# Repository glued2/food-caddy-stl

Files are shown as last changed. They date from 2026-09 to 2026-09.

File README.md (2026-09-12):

# Food caddy R4 — ALL PRINTED

**No purchased fasteners, metal pins, nuts or structural glue.** The bin,
hangers, flip hinge, axle, positive retainers, bag frame and fit-gauge keys
all print on the K1 SE. No brims or G-code.

This hangs **inside one end of the LEFT recycling bin** in the pullout
drawer, resting on the recessed internal ledge—not clamping the external
flange. The remaining recycling area stays accessible when the lid is closed.
Actual host fit, safe load and kitchen clearance remain **unverified**.

## Current print files — coupons first

- **[Full ALL-PRINTED ZIP](packages/food-caddy-r4-ALL-PRINTED-FULL.zip)**:
  three production print jobs, one combined test job, individual spares, guide and
  machine-readable validation. “Full” means a package, not one giant plate.
- **[R4 guide](docs/R4_GUIDE.md)**: read for coupon sequence, every assembly
  and removal path, keeper orientations, print orientation and local supports.
- **[Production/test plates](production)** and **[individual spares](spares)**.
- **[NO-RAILS accessory ZIP](packages/food-caddy-r4-ALL-PRINTED-NO-RAILS.zip)**:
  one combined alternative plate with liner frame, moving leaf, three standard
  keepers, long rear keeper, axle and axle-lock gate. **Excludes bin, lid, BOTH R4 hanging brackets,
  fixed rear R4 hinge rail and all coupons.** Repeat prints for identical R4
  fittings already in hand only; never compatible with R3 or legacy parts.

The complete assembly has **13 printed pieces**. The production plates
include all required quantities, including three standard keepers and one
long rear keeper. The combined test plate includes the gauge's two **short** keepers;
those short keys must not be used on the caddy.

Print `production/r4-test-fit-kit.stl` first. It combines the gauge and mating
coupons. Then print `production/r4-03-accessories.stl` and test the real fittings
on those coupons before the large `r4-01-bin.stl` and `r4-02-lid.stl` jobs.
The accessory parts sit inside the open liner frame, with at least 5 mm between
their projected footprints; no part shape or orientation has changed.
Use layer-by-layer printing, NOT sequential/complete-individual-object mode.
Localized supports must stay inside the available gaps in the slicer preview.
Individual spares remain available; they are not extra required print jobs.

### Structural redesign, not printed replacement M4 bolts

- Integral broad body dovetails and matching stopped hanger slides carry
  waste weight through sloped bearing seats. Small keys do **not** carry
  the main hanging load. No flexible snap fingers or friction-only joints.
- Solid printed bayonet keepers insert freely, then quarter-turn into
  positive withdrawal stops. A wide lid dovetail captures its moving leaf.
- An **8 mm printed axle** carries the lid only. Its integral head and
  cross-wing retain it axially; a separate **rigid axle-lock gate** prevents
  rotation back to release. A long rear keeper locks that gate in place.
- A removable continuous bag-retainer frame sits on the bin's integral
  ramped shelf. The lid really flips and seats directly on the rim.

## Dimensions and critical assumptions

| Dimension | Current design |
|---|---|
| Full assembly | **230 x 210.5 x 219 mm** |
| Body shell top / bottom | **204 x 190 / 190 x 174 mm** |
| Body height / floor | **200 / 3 mm** |
| Minimum true normal wall, including chamfers | **>=2.496 mm** |
| Straight top corner chamfer | **35 mm** |
| Internal ledge support plane | **216 mm above floor** |
| Body rim recess below support / closed projection above | **16 / 3 mm** |

**230 is total outside width INCLUDING ledges, not the host opening.**
The working opening assumption is **224, unmeasured**, leaving only **3 mm
nominal bearing each side**. The reported 18 mm ledge dimension is a
vertical height, not flange thickness to clamp. Exact taper, internal step,
floor datum and cabinet clearances cannot be inferred from the photo.

Measure the actual internal bearing surfaces and use the printed split
gauge and real joint coupons before spending filament on the bin. The
16 mm recess is a design choice, not a measured step. Prefer the hinge
facing the remaining recycling space; opening requires roughly **195 mm
above the internal ledge** and **54 mm behind the closed hinge end**, plus
clearance. Check the fully extended drawer, shelf/counter and adjacent bin.

## Printing and validation

K1 SE **220 x 220 x 250**, 100% scale, supplied orientations, >=2 mm
plate-edge margin. PLA on a prepared/glued bed; **no brim**. Bin and broad
flat lid pass a support-free downward-face test. Some small-part transverse
head recesses may need **localized removable supports**, as specified in
the guide. Keepers and axle print **horizontally on broad flats**, not upright.

```powershell
npm ci
npm run build
npm test
# In a Python environment with numpy and trimesh:
python source\r4\validate_stl.py
```

Source: `source/r4/generate.mjs`, pinned Manifold WASM CSG. Build writes only
current `production`, `spares`, `packages` and the existing guide bytes.
`npm test` regenerates in memory and checks exact deterministic output/ZIP
parity without rewriting. Tests cover outward single solids, true wall/floor,
per-part bed contact, plate/spare identity and gaps, bearing contact, slide
and bayonet trajectories, positive stops, gate anti-rotation, lid seating
and a full 0–110° movement sweep including all retainers.
See [validation](packages/r4-validation.json) and [manifest](packages/r4-manifest.json).
No mesh is silently repaired. CAD checks are not physical print success,
a load rating, layer-bond validation or a PLA creep-life guarantee.

## Two preserved alternatives — do not mix fittings

**[metal-screws-required](metal-screws-required/FALLBACK_NOTE.md)** contains the
complete valid-but-hardware-dependent **R3 fallback** from commit
`b736c3d7db481300fadee53dfdf104b7b42ae97f`. All 59 original source/doc/STL/ZIP
and dependency files are preserved byte-for-byte with hashes. Its build runs
from that folder; use its small `RUN_AUDIT.py` wrapper for the independent
audit in its new nested location. This fallback is not the unsafe legacy set.

**[archive/legacy](archive/README.md)** retains the 22 much older files with
known unsafe geometry. Those are historical reference only, not print
recommendations. The independent audit verifies both snapshots remain intact.

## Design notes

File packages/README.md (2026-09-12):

# Current R4 all-printed packages

- `food-caddy-r4-ALL-PRINTED-FULL.zip`: all production parts/coupons,
  three production jobs, one combined test job, individual spares, guide,
  manifest and validation. Start in the `production` folder; spares are optional.
- `food-caddy-r4-ALL-PRINTED-NO-RAILS.zip`: one combined alternative plate:
  liner frame, moving leaf, three standard keepers, long rear keeper, hinge
  axle and axle-lock gate. **Excludes bin,
  lid, BOTH new R4 hangers, fixed R4 hinge rail and all coupons.**
  For repeat prints with identical R4 fittings already printed, never R3.
- `r4-manifest.json`: full-design quantities, hashes and inventory. The
  accessory ZIP includes this catalogue for reference, not all listed parts.
- `r4-validation.json`: actual geometry, bearing, assembly path, retention,
  print-layout and opening checks.

Every fastening, including test-gauge keys, is printable. No bought hardware,
structural glue, brim or G-code. Read `../docs/R4_GUIDE.md` before printing.

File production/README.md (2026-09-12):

# R4 all-printed production and test plates

1. `r4-test-fit-kit.stl`: host gauge, its two short keys and all mating coupons.
2. `r4-03-accessories.stl`: liner frame and every small production fitting.
3. After the gauge and real fittings pass the guide's checks, print
   `r4-01-bin.stl` and `r4-02-lid.stl`, one job each.

The three production jobs contain all 13 required printed pieces. No metal
hardware or structural glue is needed. Use the supplied orientations;
read `../docs/R4_GUIDE.md` for localized support decisions and assembly order.
There is no brim or G-code. No R3/legacy part is compatible.

Use layer-by-layer printing, not sequential printing. Accessories are nested
inside the frame opening without changing their shapes or orientations.
Keep localized supports within the checked gaps; inspect toolpaths in Creality
Print before printing. Use `alternatives/r4-03-accessories-no-rails.stl` INSTEAD
of the full accessories plate only when reusing identical R4 rails.

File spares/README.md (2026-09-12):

# R4 all-printed individual parts and coupons

One STL is one physical copy. Complete caddy quantities are in
`../packages/r4-manifest.json`: notably **3 standard bayonet keepers** and
**1 long rear-gate keeper**. The two **short** gauge keepers belong only to
the host test gauge and must never replace a production keeper.

All parts are already in print orientation. Plates in `../production`
reuse these exact solids by translation. See `../docs/R4_GUIDE.md`.

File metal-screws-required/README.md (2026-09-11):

# Food caddy STL — corrected R3

## Current R3 files only; print fit coupons before the bin

This is an **inset suspended food caddy inside one end of the LEFT recycling
bin in a pullout kitchen drawer**, not an external rim clip. The hanging
ledges rest on the host's **recessed internal bearing ledge** without clamping
its broad outer flange. The roughly 200 mm caddy occupies about one end of
the 400 mm host; the remaining recycling area stays accessible when closed.
Exact usable volume and clearances depend on the actual host.

**Legacy files are UNSAFE historical reference, not current print files.**
All 22 original tracked files—old STL parts, generator, original documentation,
STL ZIP and historical G-code ZIPs—are preserved under
[`archive/legacy`](archive/legacy). Preservation hashes and the original Git
commit are recorded in [`archive/legacy-manifest.json`](archive/legacy-manifest.json).
Their thin/collapsed chamfer walls, overlapping or inverted
shells, and mismatched fittings are not fixed by slicer mesh repair.
**Do not reuse the previously printed hangers or hinge rail with R3.**

R3 is real manifold-3d solid CSG, with separately bolted hanging ledges,
a flat lid and separate hinge leaf, a **metal M5 bolt/locknut axle**, and a
continuous liner frame. It does not depend on glue or a printed friction pin.
**Metal hardware is required**, not included in STL downloads.

- **[Full R3 ZIP](packages/food-caddy-r3-FULL.zip)** — all parts,
  small fit coupons, separate printable plates, guide and validation.
  “Full” means a package of print jobs, not a crowded single plate.
- **[R3 assembly/printing guide](docs/R3_GUIDE.md)** — dimensions, required
  hardware, coupon sequence, supports and limitations. Read this first.
- **[Production/test plates](production)** — five production
  jobs and two test jobs. Import centred, at 100%, millimetres.
- **[Individual parts / spares](spares)** — seven production
  parts plus seven coupons, each in its intended print orientation.
- **[NO-RAILS accessory-only ZIP](packages/food-caddy-r3-accessories-NO-RAILS.zip)**
  — **liner frame and moving hinge leaf ONLY**. Excludes bin, lid, **both
  hanging ledges/brackets, fixed rear hinge rail**, coupons and all hardware.
  This is for identical R3 rail reuse, never old fittings, and is not a
  complete caddy.

The root now contains only the new design's `source/r3`, `docs`, `production`,
`spares` and `packages`; **the archive is not a source of usable spare parts**.
The hanging bin, hinged lid and removable bag-retainer functions are retained.
Significant changes are mechanical M4 mounting joints, a positively retained
metal M5 axle instead of a printed pin/collar, and wholly new hanging/hinge
fittings. No artificial compatibility with already printed legacy parts is
maintained. No-rails means omitting **new R3** rails for repeat prints only.

### Confirmed measurements versus assumptions

230 mm is the host's **total outside left/right width including ledges**,
NOT its clear opening. Actual clear opening is **unmeasured**. R3 assumes
224 for design checks; its ledges span 230 overall (only 3 mm nominal
bearing each side), below-ledge bracket envelope is 220, bin top is
212 x 194, base 192 x 176, body height 205. Corners use 35 mm chamfers.
Full closed assembly is **230 x 206.5 x 224 mm**. The body rim is deliberately
recessed **16 mm below the internal support plane**, keeping the entire
closed assembly, including hardware, **at most 3 mm above that plane**;
the floor is 221 mm below it. This recess is a design choice, not a dimension
measured from the photo. Height relative to the host's outer rim is unknown.

Body wall is a true 2.5 mm polygon offset, giving **minimum 2.4946 mm
normal thickness including tapered chamfers**, with a 3 mm floor.
Lid skin is 2.4 mm, seats directly at rim height, and prints with over
39,000 mm² actual flat contact on the bed.

These dimensions do **not** establish real host fit or safe loading. The
user's approximate “just over 210 at depth 230” and 18 mm ledge height
do not describe the whole taper or ledge profile; 18 mm is a vertical height,
**not flange thickness to grip**. Drawer/shelf clearance and lid-opening
space at the chosen end are also unmeasured. Measure these and test
the split full-span gauge, wall joints and complete small hinge assembly
**before spending filament on the bin**. No physical fit, load rating,
creep life or slicer validation is claimed.

### Slicing summary

K1 SE: 220 x 220 x 250. Supplied layouts have >=2 mm XY edge margin.
PLA on a correctly prepared/glued bed. **No brims, no new G-code.**
Bin and broad flat lid: supports off. The fixed rear hinge rail's horizontal
5.8 mm bores need localized removable supports; other small-part horizontal
M4 holes may need local support depending on coupon results. Use the supplied
orientations and read the full guide. Do not automatically lay hangers on
their projecting ledge tips.

### Source and validation

```powershell
npm ci
npm run build
npm test
# Independent audit, in an environment with numpy and trimesh:
python source\r3\validate_stl.py
```

The generator is `source/r3/generate.mjs`; dependencies are pinned in
`package-lock.json`. It writes directly to `production`, `spares` and `packages`
using a single file manifest, never into `archive`. `npm test` rebuilds in
memory and fails on stale files.

Automated checks cover valid closed outward single-part solids; true
chamfer offsets and continuous floor; individual bed contact; printer margins;
plate separation and translated spare identity; lid seating and assembly
collisions; 0–110° opening at 0.1° intervals; metal axle clearance and positive
retention dimensions; archive parity. Details are in
[`packages/r3-validation.json`](packages/r3-validation.json).
The independent Python audit checks the exported STL topology/winding/volume,
per-component bed contact, triangle-level plate/spare parity, manifest/ZIP
hashes and complete archive preservation against its immutable baseline.
Neither test substitutes for physical
fit, layer adhesion, stress analysis or a slicer preview.

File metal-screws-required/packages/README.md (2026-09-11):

# Current R3 packages

- `food-caddy-r3-FULL.zip`: all seven production parts, seven coupons,
  five production plates and two test plates, guide, manifest and validation.
  This is a package of separate print jobs, not one oversized plate.
- `food-caddy-r3-accessories-NO-RAILS.zip`: **liner frame and moving hinge
  leaf only**. Excludes bin, lid, **both new hanging brackets/ledges and
  the new fixed rear hinge rail**, coupons and all metal hardware.
  Only for repeat prints reusing identical R3 fittings—never archived parts.
- `r3-manifest.json`: full current file inventory and SHA-256 hashes.
  The accessory ZIP includes this full-design catalogue for reference;
  that catalogue does not mean the omitted parts are in the accessory ZIP.
- `r3-validation.json`: dimensions and automated CSG/print/assembly checks.

Read `../docs/R3_GUIDE.md`, measure the unconfirmed host opening, then print
coupons first. Hardware and localized hinge-bore supports are required.
No new G-code or brims. No physical fit or load rating is claimed.

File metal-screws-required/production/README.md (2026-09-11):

# R3 production and test plates

Print the two test jobs and actual small fittings first, then the bin, lid and
liner frame only after checking fit. The five production jobs are separate
plates, not one oversized assembly. Each physical part also exists as an
individual replacement in `../spares/`.

Read [`../docs/R3_GUIDE.md`](../docs/R3_GUIDE.md) for hardware, orientations and
localized supports. No brims or G-code. Old files are isolated in
`../archive/legacy/` and must not be printed or reused with R3.

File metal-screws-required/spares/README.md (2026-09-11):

# R3 individual parts, spares and fit coupons

These 14 STLs comprise seven production parts and seven small coupon parts.
Each is already in its intended print orientation. Production plates in
`../production/` reuse the identical solids, so do not print both unless you
want extra copies.

Read [`../docs/R3_GUIDE.md`](../docs/R3_GUIDE.md) before printing or assembly.
**No R3 part is intended to mate with an archived legacy fitting.** The
no-rails accessory package omits NEW R3 rails for repeat prints only.

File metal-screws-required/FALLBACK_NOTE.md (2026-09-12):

# Preserved R3 fallback — metal screws required

This is the complete R3 deliverable from commit
`b736c3d7db481300fadee53dfdf104b7b42ae97f`, preserved without changing any
original source, STL, ZIP, documentation or dependency-manifest bytes.
`PRESERVATION.json` records all 59 original files and hashes, including a
copy of the original historical archive. The root historical archive was
not modified. This folder is a hardware-dependent fallback, **not the unsafe
legacy design** inside its archive subfolder.

From this folder, `npm ci`, `npm run build`, and `npm test` run normally.
`npm test` is non-writing. To regenerate without changing the preserved
snapshot hashes, first copy this fallback to a separate working folder:
the original generator writes its local outputs and may change ZIP container
timestamps even when the STL geometry is identical.
For the independent audit, use a Python environment containing numpy/trimesh:
`python RUN_AUDIT.py`. The original audit assumes it is at the Git repository
root; this small wrapper adds `git ls-tree --full-tree` for the new nested
location only. The original audit source is unchanged.

The current root R4 design is all-printed. Do not mix R3 and R4 fittings.

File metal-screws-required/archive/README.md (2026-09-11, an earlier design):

# Unsafe historical files — do not print

`legacy/` contains the complete pre-R3 tracked repository: old STL parts,
old generator, original README/assembly notes, STL ZIP, and historical
G-code ZIPs. These are preserved for traceability, **not recommended files**.
Instructions inside that snapshot are obsolete and unsafe to follow.

Use only the current root `production/`, `spares/`, `packages/`, `source/r3/`
and `docs/R3_GUIDE.md`. R3 is a different design; **no old hanging or hinge
fitting is compatible**. No-rails packages refer only to identical R3 fittings.

`legacy-manifest.json` records all 22 original paths, their archived paths,
byte lengths, SHA-256 hashes and immutable source commit. Binary assets and
the old generator were moved without changing their working-tree bytes.
Original README/assembly notes were recovered byte-for-byte from the original
Git commit, before the R3 documentation rewrite. The STL audit verifies the
archive against both these preservation hashes and the immutable Git baseline.

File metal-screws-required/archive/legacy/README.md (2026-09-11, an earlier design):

# Food caddy STL

Parametric food-caddy parts sized for the Creality K1 SE.

## Print set

All files are now the current, standard design (after the reinforcement update following the first test print). Print these as separate jobs from `production\`:

1. `food_caddy_k1se_body_216mm.stl` - not yet printed.
2. `food_caddy_k1se_flip_lid_216mm.stl` - not yet printed; the rear hinge spine and front seating tab now have wider, full-thickness base pads so they can't shear off the lid skin the way the retainer frame tab did.
3. `food_caddy_k1se_liner_hanger_plate.stl` - bag-retainer frame is now a uniform 2.8 mm thickness with flush grip tabs, and the collar is printed standing on its round face so its pin bore is vertical.
4. `food_caddy_k1se_hinge_kit_plate.stl` - unchanged; the rear hinge rail already printed successfully, and this plate also contains the hinge pin.

Alternative accessory plates, useful if you don't want to reprint parts that already came out fine:

- `food_caddy_k1se_accessories_everything.stl` - every small part on one plate: bag-retainer frame, hanger ears, collar, hinge rail, and hinge pin.
- `food_caddy_k1se_accessories_no_rails.stl` - everything except the hinge rail, since the rail already printed successfully. Contains the bag-retainer frame, hanger ears, collar, and hinge pin.
- `food_caddy_k1se_failed_parts_only.stl` - just the two parts that actually failed on the first print: the bag-retainer frame and the collar.

The complete package is also available as `food-caddy-k1se-stls.zip`. Replacement parts are in `spares\`. Assembly and printing guidance is in `docs\ASSEMBLY_NOTES.txt`.

The G-code ZIP files are retained as historical artifacts. The recommended workflow is to import the production STLs into Creality Print and slice them using the actual printer and filament profiles.

## Source

The generator is in `source\generate_food_caddy_stls.js`.

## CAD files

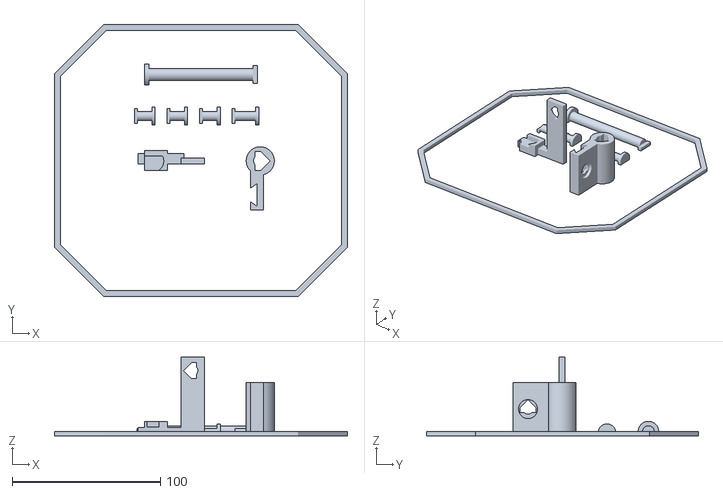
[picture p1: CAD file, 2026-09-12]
alternatives/r4-03-accessories-no-rails.stl
197.7 x 183.7 x 53.0

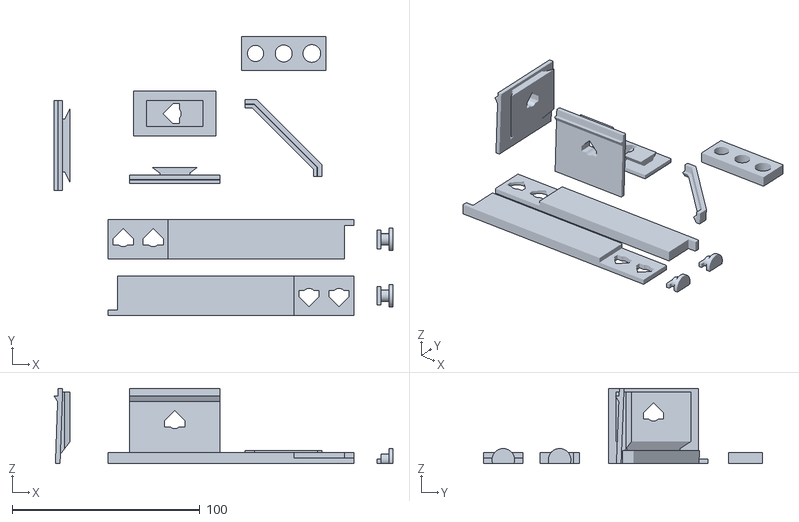
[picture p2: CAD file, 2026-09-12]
production/r4-test-fit-kit.stl
180.5 x 148.5 x 40.0

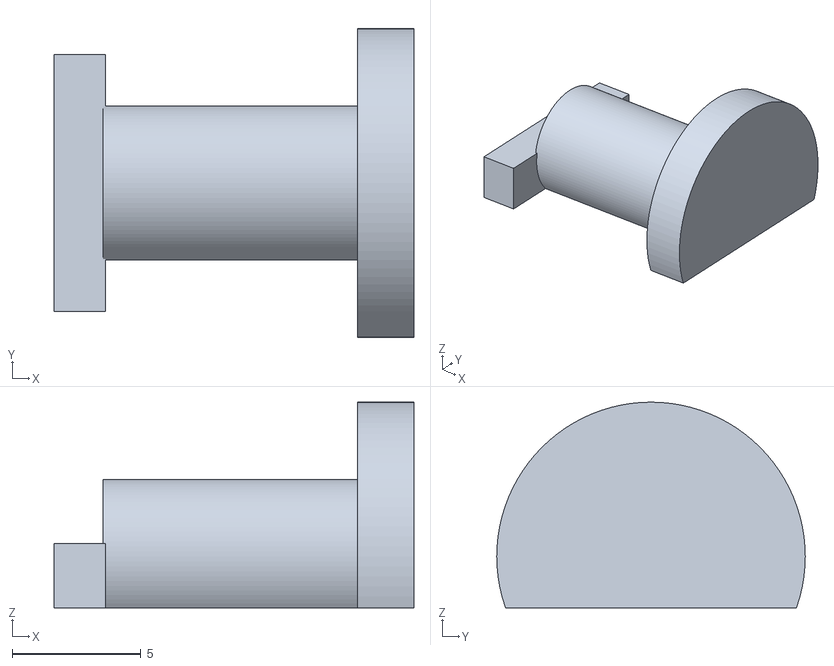
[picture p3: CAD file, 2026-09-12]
spares/r4-bayonet-keeper.stl
14.0 x 12.0 x 8.00

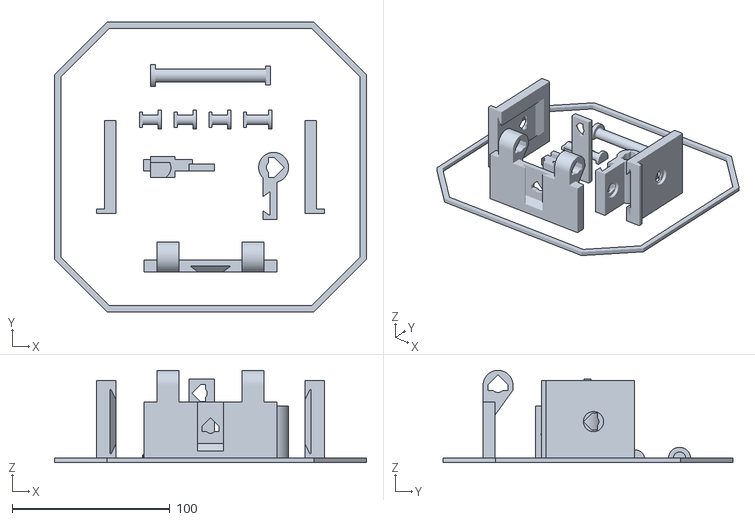
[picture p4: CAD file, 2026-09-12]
production/r4-03-accessories.stl
197.7 x 183.7 x 58.5

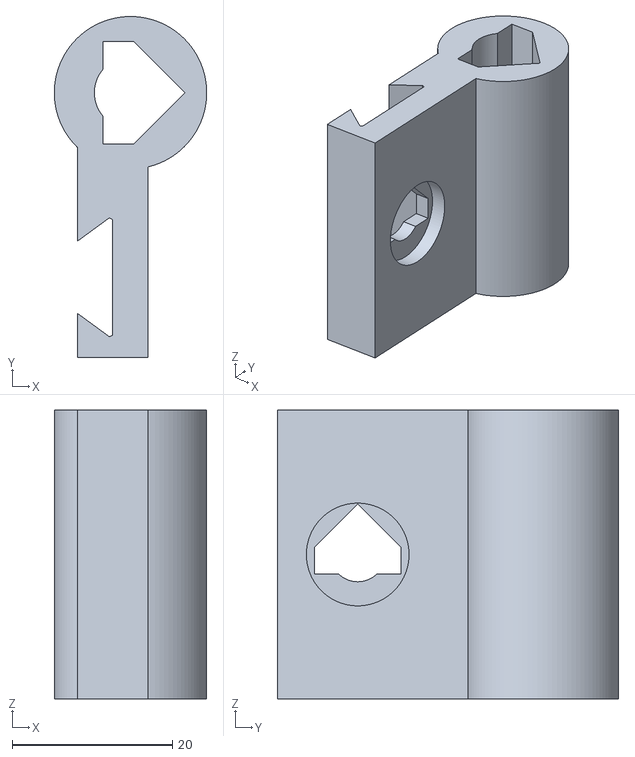
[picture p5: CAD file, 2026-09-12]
spares/r4-hinge-leaf.stl
19.0 x 42.5 x 36.0

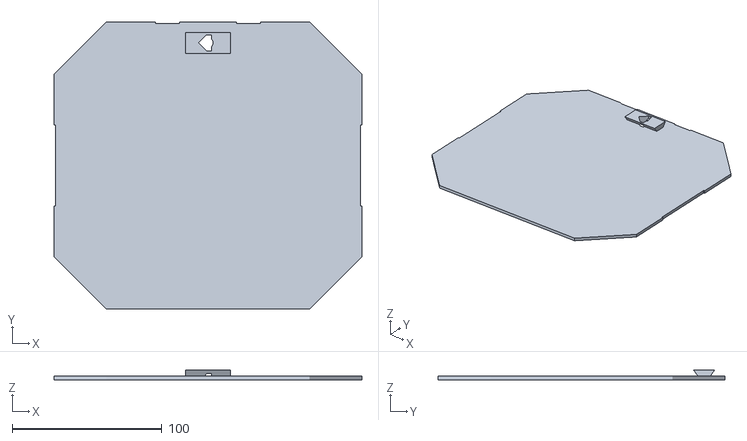
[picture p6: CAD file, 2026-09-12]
production/r4-02-lid.stl
206.0 x 192.0 x 6.40

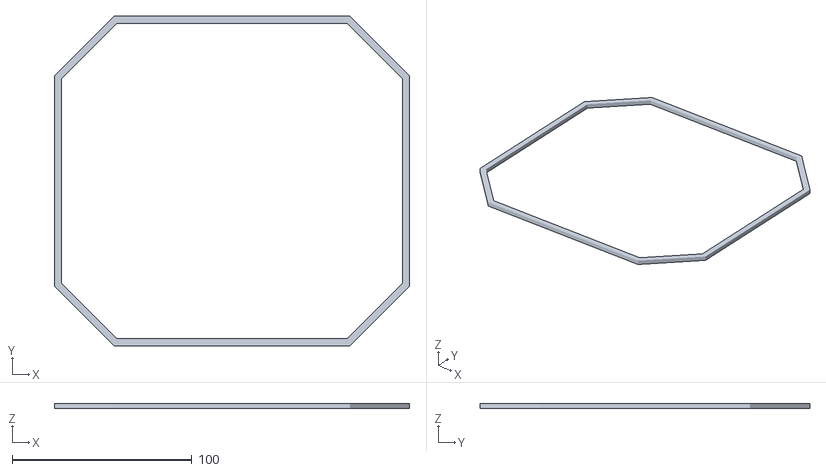
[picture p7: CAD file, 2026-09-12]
spares/r4-liner-frame.stl
197.7 x 183.7 x 3.00

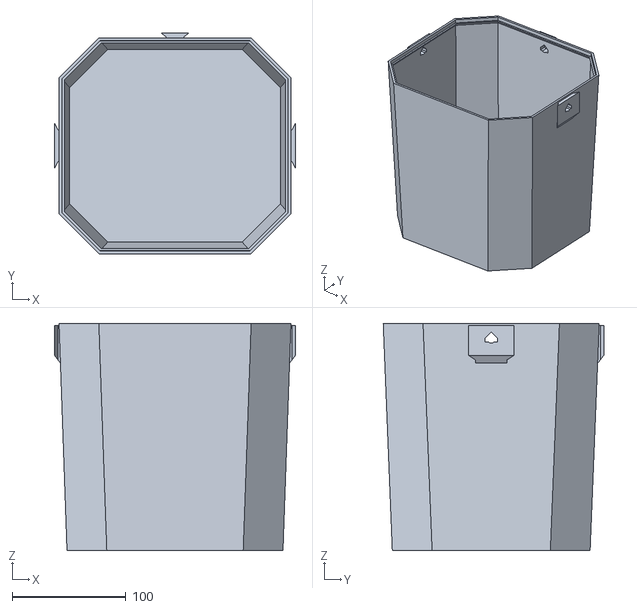
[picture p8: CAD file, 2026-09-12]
production/r4-01-bin.stl
212.0 x 194.0 x 200.0

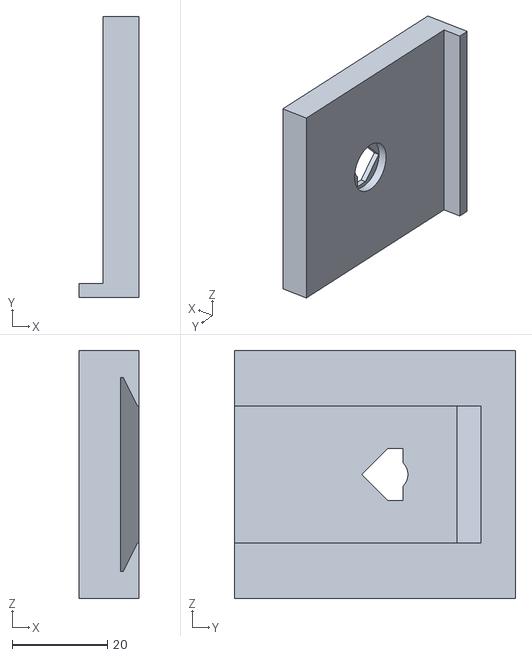
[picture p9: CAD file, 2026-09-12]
spares/r4-hanger-left.stl
12.5 x 59.0 x 52.0

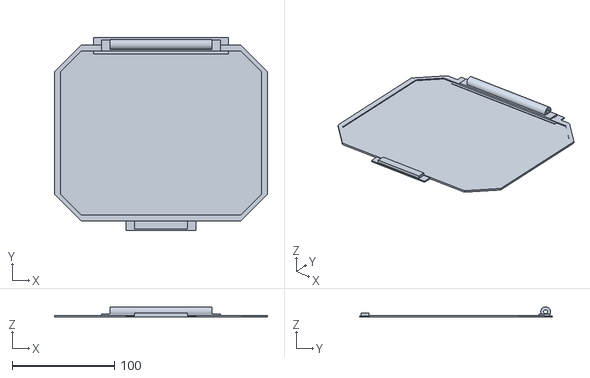
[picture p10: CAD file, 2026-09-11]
production/food_caddy_k1se_flip_lid_216mm.stl
208.0 x 188.0 x 10.1

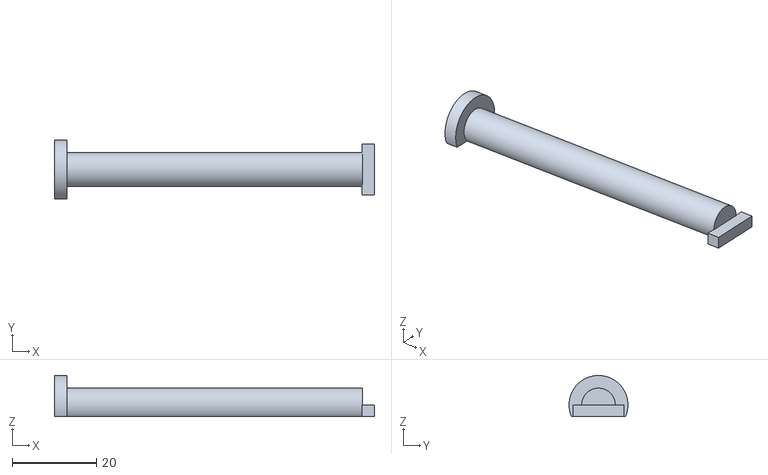
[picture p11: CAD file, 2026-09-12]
spares/r4-hinge-axle.stl
76.0 x 14.0 x 9.75

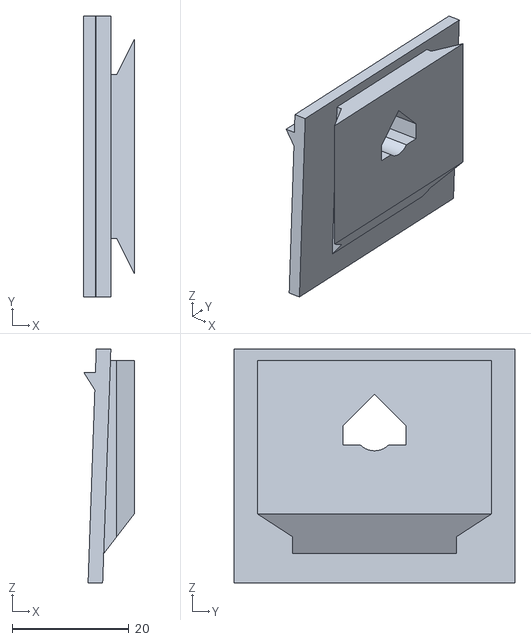
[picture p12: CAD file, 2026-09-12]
spares/r4-coupon-side-joint.stl
8.64 x 48.0 x 40.0

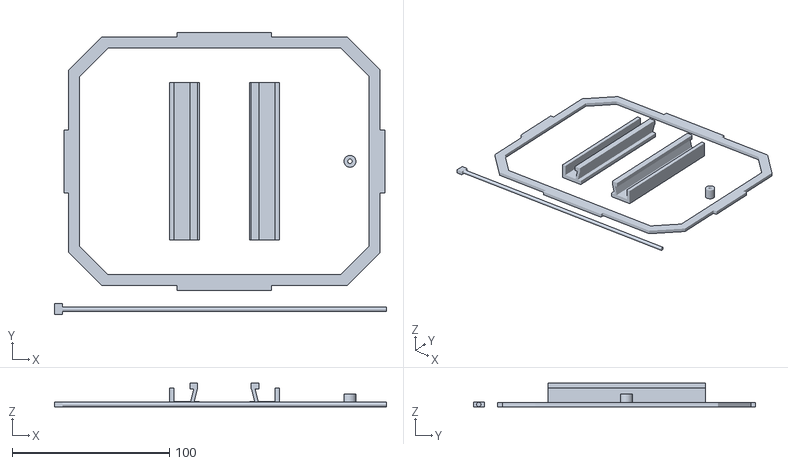
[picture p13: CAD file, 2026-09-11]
production/food_caddy_k1se_accessories_no_rails.stl
211.0 x 179.5 x 15.0

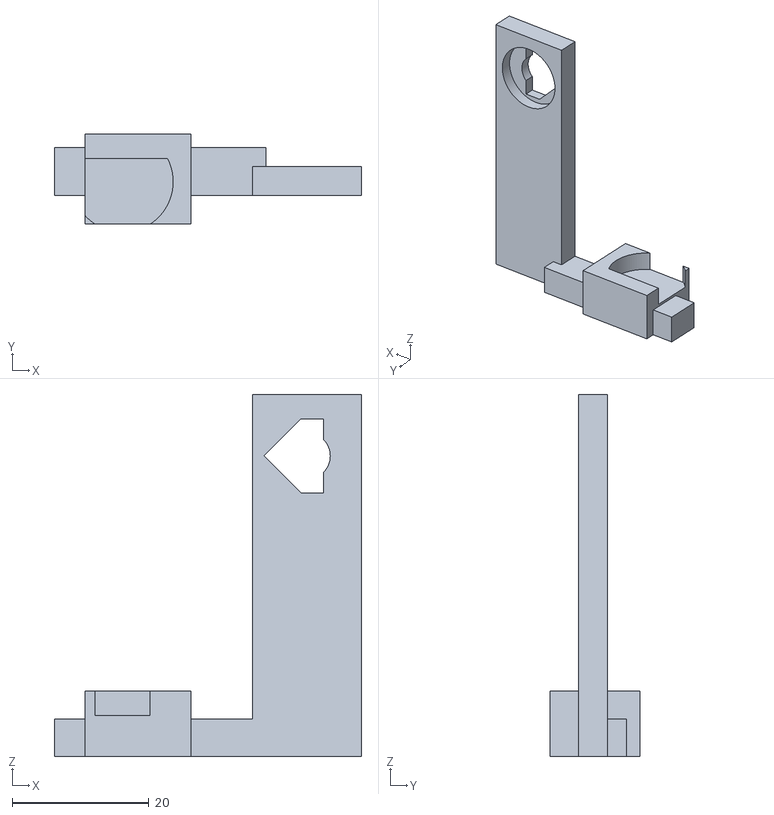
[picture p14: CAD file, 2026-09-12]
spares/r4-axle-lock-gate.stl
45.0 x 13.2 x 53.0

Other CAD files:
production/food_caddy_k1se_flip_lid_216mm_bed_centered.stl
production/food_caddy_k1se_liner_hanger_plate.stl
spares/r4-coupon-rear-joint.stl
production/food_caddy_k1se_accessories_no_rails_bed_centered.stl
metal-screws-required/archive/legacy/production/food_caddy_k1se_accessories_everything.stl
metal-screws-required/archive/legacy/production/food_caddy_k1se_accessories_everything_bed_centered.stl
metal-screws-required/archive/legacy/production/food_caddy_k1se_accessories_no_rails_bed_centered.stl
metal-screws-required/archive/legacy/production/food_caddy_k1se_body_216mm.stl
metal-screws-required/archive/legacy/production/food_caddy_k1se_body_216mm_bed_centered.stl
metal-screws-required/archive/legacy/production/food_caddy_k1se_failed_parts_only.stl
metal-screws-required/archive/legacy/production/food_caddy_k1se_flip_lid_216mm_bed_centered.stl
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

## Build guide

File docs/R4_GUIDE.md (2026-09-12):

# R4 ALL-PRINTED food caddy — measure and print coupons first

**Every assembly part, axle, keeper and gauge fastening is printed. No bought
fasteners, metal pins, nuts, elastic bands or structural glue are required.
No brims or G-code are supplied. This is an untested physical prototype:
CAD validation is not a load rating, a successful print, or proven host fit.**

## Installation and dimensions

This is a suspended inset caddy occupying one end of the **LEFT recycling bin
in the pullout drawer**, leaving the other end accessible for recycling when
closed. Hangers rest freely on the recessed **internal bearing ledge**; they
do not clamp the broad external flange. The photo establishes this arrangement,
not numerical opening, step or cabinet clearances.

All dimensions are mm:

| Item | R4 design |
|---|---|
| Complete installed hanging span | **230**, including both ledges, NOT the clear opening |
| Host opening used for design | **224 assumed, unmeasured** |
| Nominal bearing against that assumption | Only **3 per side**, across 52 front/back length |
| Body shell top / bottom / height | **204 x 190 / 190 x 174 / 200** |
| Body integral rail maximum width | 212 (prints with >=4 mm side margin) |
| Hanger faces below ledges | 220 outside span |
| Straight top corner chamfers | 35, not rounds |
| True horizontal polygon wall offset | 2.5, normal thickness >=2.496 including tapered chamfers |
| Floor | 3 continuous, joined to walls and rail roots |
| Lid flat skin | 206 x 192 x 2.4, with small edge reliefs and an integral slide rail |
| Internal support plane / ledge top | Z=216 / Z=219 |
| Body rim | Z=200: recessed 16 below support |
| Closed assembly | **230 x 210.5 x 219** |
| Closed height above internal ledge / floor below | **3 / 216** |
| Hinge axis | Y=105, Z=209; circular bore core diameter 9 |
| Printed axle | Diameter 8 circular envelope with an intentional flat for printing |

The host's measured 230 total width is not its opening. Its approximate
18 ledge dimension is a **vertical height, not a thickness to clamp**.
The host is slightly tapered, just over 210 wide at 230 depth; exact widths
at intervening heights, bottom datum and chamfer positions remain unknown.
Measure floor clearance **216 below the actual internal bearing plane**,
not from an assumed external rim. The 16 recess is a design choice, not a
measurement extracted from the photo.

The host has 400 front/back available; the caddy occupies approximately 211.
Nominal remaining length is not a claim about usable volume or accessibility
around an actual bag. Prefer the accessible end with the hinge facing the
remaining recycling area, not tight against the host end wall. The open lid
temporarily sweeps above that area.

The computed 0–110 degree opening envelope is approximately **195 above
the internal support plane** and **54 behind the closed hinge end** (rounded
up; add real clearance). See `packages/r4-validation.json` for sampled values.
The cabinet, shelf/counter, adjacent right bin and drawer front are NOT in
the CAD collision model. Check with the drawer fully pulled out; do not
assume either drawer closure or lid opening is possible without measurements.

## Mechanism: printed solids, not substitutes for M4 screws

### Main suspension load path

The body has integral broad male dovetail rails on each side. Each hanger
slides **up from below**, around its matching rail, until the continuous
sloped bottom seat meets the body rail's underside. The seat slope is 1.3
vertical to 1 horizontal and is printable with the bin without supports.
The downward bin load is carried by these broad seats and the captured
dovetail flanks—not by friction, flexing snap fingers or the small keepers.
Each main seat has over 90 mm² **vertical projected bearing area**; actual
surface area is greater because it slopes. The exact computed areas appear
under `intentionalContacts` in the validation report.

The host ledge bearing remains only an assumed 3 x 52 per side. This is not a
safe-load calculation. If the real bearing is narrower, rounded, sloped,
flexible or insufficiently engaged, STOP and change the design after measuring.

The rear hinge rail uses the same stopped slide principle with a narrower
rail. The lid has a separate wide printed dovetail that slides sideways into
the moving hinge leaf. These fittings are new R4 parts, not R3-compatible.

### Solid printed bayonet keepers

Three standard keepers lock the two hanger slides and the lid/leaf slide.
One **long rear keeper** locks the rear rail together with the axle-lock gate.
The two much shorter keepers are **for the host gauge only**.

Each keeper has a 6 mm shaft envelope, broad integral D-shaped head, and
solid cross-wing at its inner end. Insert with the wing aligned with the
keyed opening, fully seat the head, then turn it **90 degrees**. Its inner
wing then physically blocks straight withdrawal. This is not a friction-fit
collar or a tiny flexible barb. Small clearance/play is intentional.

The printed head has a flat edge which acts as an orientation indicator.
With the wing aligned for insertion, that edge is parallel to the broad
lower edge of the keyed opening; when locked it is perpendicular. In the
assembled bin, the tested locked D-flat faces:

| Keeper | Flat faces |
|---|---|
| Right hanger | Rear of bin (+Y) |
| Left hanger | Front of bin (-Y) |
| Long rear keeper | Left (-X) |
| Lid keeper | Rear (+Y) |
| Two short gauge keepers | Left along the assembled gauge (-X) |

These are deliberate-turn rigid keys, **not self-latching detents**. Check
the flats are locked and gently pull-test them before hanging or emptying
the caddy. Never rely on tightness to determine retention. If they can pull
straight out while locked, the print/fit has failed. Do not force, glue,
heat-weld or substitute metal hardware to rescue a bad fit.

### Printed hinge axle and positive anti-rotation gate

The low-load hinge carries the lid only, not the waste-bin load. Its printed
axle is much larger than the old small pins: 8 mm envelope with a flat bottom,
printed with its **long axis horizontal**. It runs in complete 9 mm circular
cores with a keyed extension; the extension removes material, never intrudes
into the circular core.

Fixed barrels span X=-34..-20 and 20..34. Moving leaf spans -18..18, leaving
2 gap each side. Shaft runs -34..36; integral head -37..-34; distal wing
36..39. Insert from the left with the wing aligned, rotate so the D-head's
flat faces rear (+Y), then fit the **separate axle-lock gate** from the left.
The gate captures the D-head: it prevents the working hinge from turning
the axle back to its release orientation and limits axial withdrawal.
The long rear keeper then pins that gate to the rear rail/body joint.
**Never operate the hinge without the gate and its locked long keeper.**

This retains a genuine flip hinge and removable bag frame. It is not a
lift-off lid, an external rim clamp, or an assembly of printed M4 fasteners.
There is no latch or built-in opening hard stop; limit use to the tested
0–110 degree range, subject to the actual kitchen clearance.

## What to print

`packages/food-caddy-r4-ALL-PRINTED-FULL.zip` is a package of separate print
jobs, not a crowded single plate. All individual spares are in `spares`.

| Production plate | Contents |
|---|---|
| `production/r4-01-bin.stl` | 1 bin, integral body rails and liner shelf |
| `production/r4-02-lid.stl` | 1 flat lid with integral leaf slide rail |
| `production/r4-03-accessories.stl` | Frame, both hangers, fixed rail, moving leaf, gate, 3 standard keepers, 1 LONG keeper and axle |
| `production/r4-test-fit-kit.stl` | Both gauge halves, 2 SHORT gauge keepers, and all 5 mating/corner/bore coupons |

This reduces six production jobs to **three**, and two test jobs to **one**.
The main bin and lid remain separate; all smaller production pieces fit inside
the liner frame's empty centre. Only layout translations changed, not geometry
or print orientation. Every projected footprint has at least 5 mm clearance.
Print layer by layer, **not sequentially by complete object**; otherwise the
toolhead can hit a tall fitting. Check localized support expansion in the slicer
preview: a part-gap check does not certify generated support/toolhead paths.

There are **13 production pieces**, representing 11 individual part types.
The eight coupon types require nine pieces because the short keeper is
printed twice. Do not print both a plate and its individual spares unless
you want extra copies.

Distinguish keeper lengths before assembly: standard 14 overall, long rear
18.2, short gauge 8.4 (all share the broad D-head). Short gauge keys must
NEVER be used on the loaded assembly. Quantities are also in
`packages/r4-manifest.json`.

### NO-RAILS option

`packages/food-caddy-r4-ALL-PRINTED-NO-RAILS.zip` contains one alternative plate,
`alternatives/r4-03-accessories-no-rails.stl`, with the **liner frame, moving
hinge leaf, three standard keepers, long rear keeper, hinge axle and axle-lock
gate**. Use it instead of the full accessory plate, not in addition. It excludes:

- the bin and lid;
- **BOTH new R4 hanging ledges/brackets**;
- the **fixed rear R4 hinge rail**;
- all fit coupons and short gauge keepers.

It is only for repeat prints reusing identical R4 body/lid/rails already in
hand. It does not work with R3 metal-screw fittings or unsafe legacy rails.
The alternative plate already includes three standard keepers. Each individual
spare STL represents one keeper. The included manifest describes
the whole design, not additional contents secretly present in this ZIP.

## Fit-first sequence and collision-checked assembly paths

1. **Measure the host before the big bin.** Record the internal opening,
   actual flat bearing widths, internal-to-outer-rim step, ledge height,
   taper at the proposed bottom and rail depths, floor clearance, corners,
   drawer closure and opening sweep. Do not use the 230 outside measurement
   as the opening.
2. Print `production/r4-test-fit-kit.stl`. Separate the two gauge halves and
   two short keys from the five mating coupons. Mate the central half-thickness tabs by
   bringing the right half against the left along the front/back direction.
   Align BOTH holes, insert the two **short** keys, then quarter-turn them.
   There is no purchased fastening. The assembled gauge spans 230 at the
   tips and 220 below, with an 18-deep vertical sample and 3-thick top tips.
   Rest tips on the **internal** ledge, not the external flange. Check square
   alignment and drawer closure gently. This is not a full tapered-bin,
   56-deep hanger, 216-deep floor or load test.
3. Print `production/r4-03-accessories.stl`, containing the frame and all actual
   small production fittings. Use the mating coupons from the test kit.
   Assemble the side/rear coupons with their real rails,
   and leaf with the lid coupon. Print orientation and clearance must match
   the production parts. Bore coupon holes are 8.6, **9.0**, 9.4 left-to-right;
   the centre is the production circular core. It checks diameter only:
   test bayonet wings, gate and complete hinge on the real small fittings.
4. On the side coupon, start the hanger below the male rail and slide it
   **up** to the sloped seat. Insert a standard keeper with wing aligned,
   fully seat, then quarter-turn. Check seat contact, positive capture of
   the dovetail, and blocked downward removal with the keeper installed.
   Reverse intentionally: fully reseat, unturn/remove key, slide down.
   Repeat rear coupon with rear rail; its long key is installed later through
   the gate. Do not lift by an unretained fitting.
5. On the detached lid/coupon, slide the leaf **from the right toward the
   centre**, along X, over its integral dovetail. Its base rests at the lid
   top. Fit and lock a standard lid keeper from above. Verify blocked
   lateral removal and captured lift-off. Remove only after unlocking
   that keeper; never pry the undercut apart.
6. After successful coupons, print the full bin and lid; the frame was already
   printed on the accessory plate. Install
   hangers and their locked standard keys. Slide rear rail up and hold it
   seated during hinge installation. Install the bag/frame: the frame sits
   at Z=196..199 on the integral shelf, 1 below the rim.
7. Lower the assembled lid/leaf/keeper vertically into the rear ear gap.
   With axle absent, the CAD checks a 60 mm lowering path. Insert the
   unturned axle **from the left**, through fixed/moving/fixed barrels.
   Fully seat its head and turn its flat toward the rear (+Y). The solid
   distal wing is now across the release opening.
8. Slide the axle-lock gate **from the left** over the locked D-head. Its
   open side clears the lid sweep; it is not meant to fully surround the
   entire head. Insert the **long rear keeper** through gate, rear rail and
   body, fully seat, then quarter-turn. Check that the gate cannot slide off,
   that the axle cannot turn back toward release, and that neither pulls out.
9. Check closed lid seating directly on the rim, removable frame below it,
   every keeper's locked orientation, and slow opening through only the
   available angle up to 110. CAD checks 0.1-degree intervals with ALL
   retainers present. Then check the REAL drawer and cabinet.
10. To remove the lid: support it, unlock/remove the long rear keeper,
    slide gate left, fully reseat axle, reverse its quarter-turn, withdraw
    axle left, then lift lid assembly. Rear rail is now unretained: hold it.
    Remove leaf from lid only by separately unlocking its standard keeper.

No part is supposed to be magically trapped or snapped through another:
the insertion, locking and reverse-removal directions above are modelled.
Pin/slot clearance is intentional. Verify actual motion and contact by hand;
if it requires force or sanding away a retaining wing, STOP and reparameterize
the source and rerun the tests. Do not remove structural material to make a
failed joint appear to fit.

The host's long risers need separate checking: the brackets extend from
Z=160 to the Z=216 bearing plane (56 below). The simple 18 mm host gauge
does not certify that entire depth. Hang the real bracket/side-coupon pair
inside the host too. Those coupons are interface tests, not representative
load-test specimens.

## Slicing: PLA, glued bed permitted, NO brim

Use a calibrated K1 SE **220 x 220 x 250** profile, millimetres, 100% scale.
All supplied plates are centred with at least 2 mm XY margin and 5 mm
between separate components. Do not auto-orient or scale them.

Starting geometry-aware settings, not a validated filament profile: 0.4 mm
nozzle, 0.20 mm layers, six walls for load-bearing fittings and body where
the slicer can fit them. Make the bin's 3 mm floor solid (15 bottom layers
at 0.20). Lid skin is 2.4 (12 layers); retain its solid skin. Use solid
infill for small keepers, axle, gate and load-bearing fittings. The thin
body walls are already modelled; inspect gap filling and perimeter continuity.
No brisk speed/temperature recipe is prescribed.

| Part | Supplied orientation and supports |
|---|---|
| Bin and joint/corner coupons | Floor/cut base down. **Supports OFF**: tapered walls, integral male-rail undersides, shelf and keyed hole roofs meet the 45-degree face test. |
| Lid and lid coupon | Broad flat underside at Z=0. **Supports OFF**: integral rail widens with a printable slope; holes are vertical. |
| Liner frame | Flat. Supports OFF. |
| Hangers | Flat end face down, 52 tall; sloped load-seat cross-section lies in the layer plane. Do not lay ledge tips down. Inspect the short throat bridges and keeper head recesses; localized support in recesses only if coupons need it. |
| Fixed hinge rail | Bottom edge down. Integral ramped webs support barrels; axle keyway has a 45-degree roof around a complete circular core. Inspect all bore roofs in preview; local removable bore support is permitted if your coupon quality needs it. |
| Moving leaf | Axle direction vertical, one end face down. Dovetail runs vertically. **Localized removable support may be needed in the transverse keeper head recess and hole**; never leave support inside mating surfaces. |
| Axle-lock gate | Left end down, 53 tall, as supplied. The D-head socket is open to the next layers, not bridged over. Its long-keeper head recess is transverse: support that recess locally if needed. |
| All keepers and axle | **Long axes horizontal**, flats down. They have real flat bed contact, not a round shaft balancing on a line. Supports OFF. Never print the axle upright. |
| Gauge halves and bore strip | Broad faces flat. Supports OFF unless your gauge head-recess bridges need localized help. |

Use a clean, properly prepared/glued bed; bed adhesive is not a structural
joint. **No brims, glue assembly or G-code.** If an upright narrow fitting
will not adhere without a brim, fix bed preparation/calibration rather than
using a warped part. Preview every layer and remove all localized supports
before testing fits; do not “repair” STL solids in the slicer.

## What automated checks do and do not establish

From the repository root:

```powershell
npm ci
npm run build
npm test
python source\r4\validate_stl.py
```

The Python audit needs numpy/trimesh; it is separate from the WASM generator.
Source is `source/r4/generate.mjs`, with pinned manifold-3d 3.5.1 and fflate.
One shared parameter set creates canonical parts, their translated plates,
coupons, production quantities, hashes and deterministic ZIPs. `npm test`
rebuilds in memory without rewriting anything and fails on stale files.
Changing dimensions requires all tests, documentation and physical coupons
to be revisited; arbitrary parameter combinations are not guaranteed.

Tests require finite nondegenerate triangles, closed consistently oriented
topology, positive volume, one joined solid per part, bed contact for EVERY
physical copy, exact plate/spare geometry, printer margins and plate gaps.
CSG starts from valid cross sections and convex primitives; real unions
overlap where features join, not appended touching shells. No exported mesh
is silently repaired.

Checks also cover true normal wall/chamfer offsets, continuous floor,
support-free bin/lid face angles, seat areas, zero lid float, all closed
pairwise intersections, slide-in paths, quarter-turn paths, reverse removal
directions, locked withdrawal/head stops, rail/leaf capture, the axle gate's
positive anti-rotation and axial stop, and full lid motion with every keeper.
The report enumerates intended bearing contacts and sampled paths instead
of blanket-ignoring colliding pairs.

The independent audit reads exported STLs, checks topology/volume/bed contact
and exact translated triangle identity, verifies ZIP/hash parity, and verifies
the untouched **22-file legacy snapshot plus 59-file R3 fallback snapshot**.
The fallback is `metal-screws-required`, not the unsafe `archive/legacy`.

None of this validates layer adhesion, tolerances on your printer, fatigue,
PLA creep, actual host/cabinet geometry, bag snagging or a safe waste load.
Use a liner, smooth/remove only nonstructural print burrs, inspect before
use, and test progressively over a safe supported surface. Do not hang over
people or valuables. Do not dishwasher or expose PLA to hot waste. Frequent
emptying/inspection is prudent; no service life or load rating is claimed.

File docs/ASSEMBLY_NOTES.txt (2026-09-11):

Food caddy STL assembly notes

Parts:
- food_caddy_k1se_body_216mm.stl
- food_caddy_k1se_flip_lid_216mm.stl
- food_caddy_k1se_liner_hanger_plate.stl
- food_caddy_k1se_hinge_kit_plate.stl
- food_caddy_k1se_accessories_everything.stl
- food_caddy_k1se_accessories_no_rails.stl
- food_caddy_k1se_failed_parts_only.stl
- food_caddy_k1se_bag_retainer_ring_spare.stl
- food_caddy_k1se_hinge_pin_spare.stl
- food_caddy_k1se_hinge_retainer_collar_spare.stl

Creality K1 SE:
Use the K1SE-specific files for the fewest practical print runs:
1. food_caddy_k1se_body_216mm.stl
2. food_caddy_k1se_flip_lid_216mm.stl
3. food_caddy_k1se_liner_hanger_plate.stl
4. food_caddy_k1se_hinge_kit_plate.stl

Design update after the first test print:
- The bag-retainer frame in food_caddy_k1se_liner_hanger_plate.stl now has a
  uniform 2.8 mm thickness with flush grip tabs, instead of a thinner ring with
  a raised tab that could separate when removed from the bed.
- The hinge-retainer collar is now fully round and prints standing on its flat
  circular face, so the pin bore prints vertically instead of needing a small
  side lug that printed poorly on its side.
- The lid's rear hinge spine and front seating tab now have wider, full-
  thickness base pads bonded to the lid skin, to avoid the same kind of
  shear-off failure the retainer frame tab had.
- The lid's rear hinge knuckle had a separate bug where its round tube dipped
  0.3 mm below the bed plane in the model coordinates. This forced the whole
  lid to be lifted 0.3 mm off the print bed to compensate, which is very
  likely why the first couple of layers printed badly on the test print. This
  is now fixed: the knuckle no longer dips below the lid skin, so the lid
  sits flush on the bed.
- Alternative accessory plates are available if you don't want to reprint
  parts that already succeeded:
  - food_caddy_k1se_accessories_everything.stl: bag-retainer frame, hanger
    ears, collar, hinge rail, and hinge pin all on one plate.
  - food_caddy_k1se_accessories_no_rails.stl: the same, minus the hinge rail,
    since the rail already printed successfully on the first attempt.
  - food_caddy_k1se_failed_parts_only.stl: just the bag-retainer frame and
    collar, i.e. only the two parts that actually failed the first time.

Current design intent:
- Print the main bin upright, open side up.
- Do not print the main bin sideways. Sideways printing would need extensive
  support inside the bin, would make the hinge holes rougher/less accurate, and
  would put the hanging rim and bottom joint in a less useful layer orientation.
- The main bin no longer has integrated hinge barrels or vertical ribs. That
  keeps the largest print simple, upright, and support-free.
- The top lip is a shallow 8 mm tapered flare rather than a sudden horizontal
  shelf. This avoids the rounded-corner gaps/overhangs from the earlier lip and
  keeps the rim printable upright without support.
- Strength is now coming from geometry rather than bulk: thin walls, a small
  closed rim/bead, a slightly thicker floor, and separate load-bearing hanger
  and hinge parts.
- The lid is intentionally lightweight because it only acts as an odour cover.
  It uses a thin 0.8 mm skin with shallow stiffening beads rather than a thick
  solid plate.
- The body now has a shallow inner seating ledge at the top rim. The lid is
  slightly smaller than the outer rim so it sits on that ledge when closed,
  rather than relying on the hinge position alone to hold it flush.
- The rear hinge rail is a separate clip-on part. It is a U-channel that wraps
  over the rear top rim of the bin, so the main bin itself does not need hinge
  barrels or support material. It is included in the hinge kit plate.
- The previous integrated ribs were removed because they did not improve the
  useful layer direction when printed as part of the upright bin.

The package only includes K1 SE-relevant STLs. The oversized 230 mm body and
226 mm lid have been removed because they do not fit the usual K1 SE 220 x 220
mm build plate.

The K1SE body is intentionally 216 mm wide so it prints on the K1 SE with slicer
clearance. It will not
hang across the 230 mm support gap by itself. Use the two printed hanger ears
from the liner/hanger plate. Each ear is a C-channel clip: the open slot
slides sideways over the 4 mm top flange, one from the left side and one from the
right side. The thicker outside edge faces away from the caddy and becomes the
new hanging ledge. The ear slot includes a tapered guide face to match the
shallow flared rim. The small lower hook sits under the flange so the ear cannot
just lift off when you remove the liner.

Once both ears are fitted, they extend the assembled hanging width back to about
230 mm after printing, while keeping every individual print within the K1 SE
build area. If the ears feel loose, add a small drop of CA glue after test-fitting
the caddy in the kitchen bin.

Separate K1 SE spare-part files are included for the bag retainer, hinge pin,
and hinge collar in case a small part breaks or the fit needs experimenting.

Hinge:
The separate rear hinge rail has two outside hinge knuckles. The lid has one
centre hinge knuckle. First slide/press the rear hinge rail over the back rim of
the bin: the U-channel wraps over the rim, with one wall inside the caddy and one
wall outside the caddy. The small internal barbs are there to grip under the rim;
if the fit is too tight, lightly sand the barbs.

The rail hinge holes are circular. Once the hinge rail is seated on the bin, line up the lid knuckle between the two
rail knuckles, then slide the hinge pin through all three from one side. The
square head on one end stops the pin moving in one direction. Push the small
retaining collar onto the other end so the pin cannot walk out during use.

The hinge holes are 3.7 mm diameter. The printed hinge pin is 2.9 mm diameter,
leaving clearance for typical FDM print tolerances. The retaining collar is a
friction fit on the pin. If it is too tight, lightly sand the pin end; if it is too
loose, add a tiny drop of CA glue, hot glue, or a softened filament mushroom on
the very end after confirming the lid swings freely.

Printing:
- Print the body upright, open side up.
- Print the rear hinge rail separately.
- Print the lid flat, top face down or up depending on the finish you prefer.
- Print the hinge pin lying flat.
- Print the bag-retainer ring flat.
- PETG is preferred for kitchen use; PLA is fine for a fit test.

Bag retainer:
Put the liner into the caddy, fold the top of the liner over the rim, then press
the bag-retainer ring into the opening to trap the liner neatly below the lid.
The ring is sized to sit inside the newer flared rim and below the lid seating
ledge, so it should not hold the lid open. Its outer footprint is about
204 x 164 mm including the small grip tabs.

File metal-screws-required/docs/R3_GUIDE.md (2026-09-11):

# R3 corrected food caddy — print coupons first

**R3 is a new, incompatible design. Do not use previously printed hanging or
hinge parts with it. Fit, strength and slicing are NOT physically validated.
There is no load rating. Do not fill or hang a full bin until you have checked
the actual host and progressively tested the assembly over a safe surface.**

## Installation intent — suspended INSIDE the left recycling bin

The caddy occupies one end of the LEFT bin in the pullout kitchen recycling
drawer, leaving the remaining length accessible for existing recycling when
the lid is closed. It is not an external clip-on bin or a freestanding insert.
Its two hanging ledges rest freely on the host's **recessed INTERNAL ledge**.
There is no hook or clamp around the broad outer flange. The photograph
establishes this arrangement, not numerical opening, step or clearance sizes.

For a low closed profile, the caddy rim is recessed **16 mm below the internal
support plane**. The complete closed assembly extends only **3 mm above that
plane**, while the floor hangs **221 mm below it**. The 16 mm recess is an
explicit design choice, not a measured ledge step. We cannot state its height
relative to the host's outer rim without measuring that step.

Prefer the accessible end of the host, with the hinge facing the **remaining
recycling space**, not tight against the host end wall. The open lid briefly
sweeps over that remaining area; it does not permanently partition it.
The CAD opening envelope needs roughly **193 mm height above the internal
support plane** and extends roughly **59 mm behind the closed hinge end**
at up to 110°. These are caddy geometry, not photo measurements; add clearance.
The shelf/counter, adjacent right bin, drawer front and end wall are not in the
CAD collision model. Measure their clearance with the drawer fully pulled out.
**Do not assume the drawer closes or the lid opens based on these STLs alone.**

## Dimensions and assumptions (mm)

- The user's **230 is the total outside width INCLUDING host hanging ledges**,
  not the opening. This design's complete ledge span is also 230. That does
  **not** prove that it fits within/on the host: the precise host opening and
  usable bearing surfaces must be measured.
- Assumed opening: 224, **unmeasured**. Body top: 212 x 194; base: 192 x 176;
  height: 205. Top corners are straight 35 mm chamfers, not rounds. The host
  is slightly tapered, just over 210 wide at 230 depth, but its intermediate
  widths and exact corner geometry are unknown.
- Detachable hanging brackets: 60 long front/back, below-ledge outside span
  220, ledge total outside span 230, ledge underside Z=221, top Z=224.
  Nominal bearing is only **3 mm per side** against the assumed 224 opening.
  Approximate host ledge height 18 is represented by the test gauge; it is
  a **vertical height, not a thickness to clamp**. Actual bracket risers extend
  37 below the bearing surface. Verify their full depth against the host;
  the 18 mm gauge is not a full-depth bracket/host-envelope proof.
- Body interior uses a **true 2.5 mm horizontal polygon offset** on straight
  AND chamfer faces. Taper-normal thickness is at least 2.4. Floor is 3.
  The integral liner shelf ramps inward 2 over 3 height (no support).
  Wall thickness statements exclude intentional fastener holes.
- Flat lid: 214 x 196 x 2.4; underside seats on rim Z=205, no hinge float.
  Separate moving hinge leaf bolts onto the lid. Hinge axis Y=103, Z=212;
  outside barrel radius 5.5. The hinge reaches Z=217.5, lid screw tips Z=221,
  and the raised hanging ledges set the full assembled height **224**;
  depth is **206.5**. Rim Z=205 is 16 below the support plane Z=221.
  Small lid-edge reliefs clear both hanging brackets and the fixed hinge
  webs; the remaining underside still seats directly on the rim.
  Host front/back space is 400; this caddy is approximately 200, not 400.
- Liner frame: 3 thick, sits on internal shelf at Z=201, top Z=204,
  0.5 radial nominal clearance at the seating plane. Bag thickness consumes
  clearance. It lifts out through the top. It is not a structural hanger.
- Printed parts fit the K1 SE's **220 x 220 x 250** build volume with at least
  2 mm XY edge margin in the supplied centred layouts. The 230 span is
  assembled from separate parts, NEVER printed across that bed.

## Files: full does not mean one giant plate

Use only the current root **`production`, `spares` and `packages`** folders.
**Never print from `archive/legacy`**: its old geometry, code, original
instructions and G-code ZIPs are preserved historical material only.
`packages/food-caddy-r3-FULL.zip` contains all seven
production parts, all seven coupon parts, five production plates, two test
plates, this guide, manifest and machine-readable validation.

| Production job | Contents |
|---|---|
| `r3-01-bin.stl` | One bin |
| `r3-02-lid.stl` | One flat lid |
| `r3-03-liner-frame.stl` | One continuous liner frame |
| `r3-04-hanging-rails.stl` | Left AND right detachable hanging brackets |
| `r3-05-hinge.stl` | Fixed rear rail AND moving lid hinge leaf |

Every physical part also has its own `spares/r3-*.stl` individual spare, already in
print orientation. Plates reuse those exact solids by translation, not an
independent geometry implementation. `packages/r3-manifest.json` contains SHA-256 hashes.
Do not print both a plate and its individual contents unless you want spares.

**`packages/food-caddy-r3-accessories-NO-RAILS.zip` is accessory-only:** liner frame
and moving hinge leaf, supplied as individual print jobs. It explicitly
excludes the **bin, lid, BOTH hanging brackets/ledges, fixed rear hinge rail,
all coupons, and all metal hardware**. Only use it to reuse identical **R3**
rails. It is not a complete caddy and does not reuse any legacy fittings.

### Functionality retained and changed

The hanging waste bin, hinged lid and removable bag retainer are retained.
R3 deliberately replaces every old fitting rather than preserving unsafe
compatibility. The significant change is **required metal hardware**:
M4 bolted hanging/lid joints and an M5 bolt/locknut hinge axle replace
glued mounting joints and the old printed pin/collar. No-rails is solely an
option for subsequent prints that reuse **new R3** fittings. There is no
load rating, latch, opening stop or claim of physically proven host fit.

## Required nonprinted hardware — no glue structural joints

Use corrosion-resistant metal fasteners. Countersunk screws must match the
model's 90-degree head recess; verify actual head dimensions on coupons.

- Six **M4 x 16 countersunk screws**, six M4 washers (nominal 1 mm), six
  M4 nyloc nuts (allow 5 mm envelope): four for hanging brackets, two for
  rear fixed hinge rail. Heads are on the outside and must sit flush,
  especially on the hanging brackets. Nuts and washers are inside the bin.
  Check thread engagement with real hardware; do not crush PLA.
- Two **M4 x 16 countersunk screws**, two M4 washers, two M4 nyloc nuts:
  attach moving leaf to the lid. Heads sit flush in the lid underside;
  washers/nuts above the leaf. Verify actual supplier stack dimensions.
  All eight production M4 screws therefore use the same 16 mm size.
  Modelled M4 head envelope is <=8 mm diameter, washers <=9 mm diameter
  and 1 mm thick, nyloc nuts <=9.4 mm across corners and 5 mm thick.
  At least 2 mm shaft projects past each nominal nut. Real tapered inside
  walls may leave a small gap under a flat washer; tighten gently.
- One **M5 x 60 hex-head bolt**, two M5 washers (nominal 1 mm), one M5 nyloc nut
  (nominal 5 mm) for hinge axle. Full thread or suitable partial thread with
  at least enough threaded length to tighten at a 50–55 mm grip. Shaft
  length is measured UNDER the head. Do not overtighten the moving hinge.
  Validated head envelope: <=9.6 mm across corners, <=4 mm high;
  washers <=10 mm outside diameter, nut <=9.4 mm across corners.
  There is deliberately **no printed pin, friction collar or glue joint**:
  the metal bolt head and locknut give positive axial retention.
- Split host gauge only: two **M3 x 12 bolts**, washers and nuts, through
  the central overlapping half-thickness tabs. Not part of the loaded bin.

M5 axle geometry: fixed ear outer faces X=-24 and +24; inner faces -14/+14;
moving leaf spans -12..12, giving 2 mm gap per side. Bore is a complete
5.8 mm circle (96 segments), metal shaft 5.0: 0.8 diametral nominal clearance.
Washers occupy -25..-24 and 24..25, shaft -25..35, nut 25..30; 5 mm remains
past the nominal nut. The circular bores have no hidden support intrusions.

## Print sequence — stop before the full bin if any check fails

1. Measure the actual host's **internal** clear opening and usable bearing
   ledge width, vertical
   ledge height, width at the planned bin bottom and intermediate heights,
   and chamfer positions. Measure depth from the **internal support plane**,
   not an assumed outer-rim datum; floor clearance at 221 below that plane
   must be checked. Measure the step to the outer rim, closed-drawer clearance,
   and opening clearance with the drawer fully out. **230 outside is not
   sufficient information.**
2. Print `production/r3-test-01-host-gauge.stl`; bolt the two halves together
   with their centre lap faces in contact, holes aligned. Its assembled
   width is 230 across top tips and 220 below, extending 18 below the
   bearing plane. Rest the tips on the **internal ledge**, not across or
   clamped onto the exterior flange. Check actual hanger locations on both sides, with
   the gauge level. It is only a width/ledge coupon, not a tapered full
   bin envelope or a load test. A separate small corner sample is below.
   Check the gauge's 3 mm top projection against drawer closure gently;
   do not force the drawer against an obstruction.
3. Print `production/r3-test-02-mating.stl` and the **actual**
   `r3-04-hanging-rails.stl` + `r3-05-hinge.stl` small fittings.
   Test plate contains actual side/rear wall sections with matching taper
   and holes, a lid mounting patch, the actual top corner section, and a
   bore strip. Bore strip holes left-to-right are **5.4, 5.8, 6.2** in its
   supplied view; centre hole is production 5.8. Select no new production
   clearance without updating source and rerunning all checks.
4. Bolt a hanger to its side-wall sample; verify full mating-face contact,
   flush heads, washers/nuts, thread engagement and no splitting. Repeat
   rear rail on rear-wall sample. Bolt leaf to lid patch; insert M5 axle
   through fixed/moving/fixed ears with washers and locknut. Check freely
   moving hinge, axial retention, seated patch height and nut clearance.
   The corner piece is an actual short rim corner, not a complete host
   outline. Use dimensional measurements too. Tiny wall samples must be
   handled gently: they are interface checks, not representative load tests.
   Hang the real bracket/wall coupons inside the host as well: their longer
   risers represent the 16 mm inset that the simple width gauge does not.
5. Only after satisfactory dimensional checks, print bin, frame, lid.
   Install brackets/rail first; cover internal hardware smoothly with the
   liner so it does not puncture the bag. Inspect for protruding sharp
   threads. Install frame/bag, bolt leaf to lid, then install metal axle.
   Lid underside must rest on rim, frame below lid. Open only to **110°**
   maximum verified CAD sweep; no built-in hard stop is provided.
   Orient the hinge toward available open space and confirm its complete
   opening envelope clears the host and kitchen before using it.
6. Preview every layer in your slicer, inspect completed parts for gaps,
   and test gently over a supported surface. Add waste progressively, not
   all at once. Never rely on this untested PLA design above people,
   valuables or where a spill would be dangerous.

## PLA on a glued bed — no brim, no G-code

Starting settings, not a validated profile: 0.4 mm nozzle, 0.20 mm layers,
5 walls for bin, 6 for load-bearing small fittings, 6+ top/bottom layers,
25–35% infill where there is an interior (small fittings can be solid).
The 3 mm modelled floor is continuous regardless of the layer-count setting.
Use your own calibrated temperatures, speed, extrusion and shrinkage.

- **No brims. No G-code supplied.** Use a clean, appropriately glued bed.
- Bin: floor down as supplied, **supports off**. Walls taper outward very
  slightly; shelf underside is a 2:3 ramp. Mounting holes have a circular
  clearance core and 45-degree teardrop roof to avoid support inside bin.
- Lid: its broad flat **underside is at print Z=0**, supports off. Its
  countersinks widen at the bed and taper inward going up.
- Frame: flat, supports off.
- Hangers: **flat narrow end faces** down as supplied, 60 mm tall on the
  bed. This places the continuous ledge-to-wall cross-section and vertical
  hanging load in the layer plane, rather than peeling an upright-printed
  ledge off the wall. Each end has over 120 square mm flat contact.
  Do NOT lay the ledge tip down: that would leave most of the bracket
  unsupported. M4 holes/countersinks are horizontal; apply localized
  supports there if the mating test cannot bridge them cleanly.
- Fixed hinge rail: **bottom mounting edge down**, 34.5 mm tall, not axle
  vertical. Integral sloping webs support the barrel exteriors. Its round
  **5.8 mm horizontal axle bores require localized removable bore supports**
  for a dependable circular fit; inspect those supports in the slicer.
  Support horizontal M4 bores locally too if the coupon needs it.
- Moving hinge leaf: axle direction along build Z; flat end face down.
  Its axle bore is vertical and needs no support. Its M4 mounting bores
  run horizontally: localized supports only if the coupon cannot span
  4.6 mm cleanly. Remove every support fragment before fitting hardware;
  never leave material intruding into an axle bore. No global support forest.
- Coupon wall/corner pieces: short upright actual wall sections as supplied;
  teardrop holes and ledge ramps need no supports. Gauge halves: broad
  side face down; supports off. Bore strip and lid sample: flat.
- If adhesion fails without a brim, stop and correct bed preparation/profile
  rather than proceeding with warped structural parts.

PLA creeps under sustained stress and heat; no safe load or service life is
established. Do not dishwasher, expose to hot waste, or treat FDM surfaces as
certified food-contact surfaces. Use a liner, empty frequently, and inspect.

## Reproducibility and limits of automated verification

From repository root: `npm ci`, `npm run build`, `npm test`.
Source: `source/r3/generate.mjs`; pinned kernel: manifold-3d 3.5.1 WASM.
The `p` parameter block defines body size, taper, true wall offset, floor,
hinge clearance and host assumptions; mating features and coupons derive
from those shared parameters. This is one validated parameter set, not a
promise that every parameter combination will fit. Changed parameters must
pass all assertions and require regenerated guides/physical coupon tests.
Generation writes directly into root `production`, `spares` and `packages`,
never into the archived snapshot. The original generator is isolated in
`archive/legacy/source` and must not be used to generate current parts.
CSG union/difference creates actual solids, not appended overlapping shells.
Every canonical part must have kernel `NoError`, one connected solid,
closed consistently directed edges, finite nondegenerate triangles, positive
signed volume, and individual bed contact. Kernel construction from convex
primitives and boolean operations avoids the legacy self-intersecting shell
construction; topology checks alone are not offered as proof of printability.

Checks cover true polygon offsets including chamfers and tapered face normals,
the bin's support-free downward surface angles,
floor continuity, shelf bearing, rim/lid seating, assembly intersections,
complete axle and M4 screw/washer/nut clearance/retention envelopes, and a 0..110° CSG movement sweep
at **0.1° discrete intervals** (hardware sweep 0.5°, neither is a formal continuous-motion proof).
Plate clearances are checked pairwise, with exact canonical-solid reuse;
ZIP contents must byte-match the manifest's spare/production files.
`npm test` regenerates in memory and fails on stale output, without rewriting.
No mesh is silently repaired. Independent STL validation is documented in
the repository's README once run.

None of these checks measures the real host, establishes layer bonding or a
load rating, guarantees hardware tolerances, or substitutes for slicing and
physical coupon testing. Full fit remains **unverified** until you do those
checks. Legacy production/spare STL and G-code archives are unsafe historical
reference only under `archive/legacy`. `archive/legacy-manifest.json` records
preservation hashes for all 22 original tracked files; the independent audit
verifies those bytes and their original Git baseline.

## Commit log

2026-09-07 Initial commit: food caddy STL generator, models, gcode, and notes
    [food_caddy_k1se_accessories_combined_plate.stl, food_caddy_k1se_accessories_combined_plate_bed_centered.stl, food_caddy_k1se_bag_retainer_ring_spare.stl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]
2026-09-07 Clean and organize public STL package
    [food_caddy_k1se_accessories_combined_plate.stl, food_caddy_k1se_accessories_combined_plate_bed_centered.stl, food_caddy_k1se_bag_retainer_ring_spare.stl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]
2026-09-10 Add printable v2 liner and collar
    [food_caddy_k1se_hinge_retainer_collar_spare_v2.stl, food_caddy_k1se_liner_hanger_plate_v2.stl, food_caddy_k1se_liner_hanger_plate_v2_bed_centered.stl]
2026-09-10 Remove generated v2 duplicate
    [food_caddy_k1se_liner_hanger_plate_v2_bed_centered.stl]
2026-09-10 Add v2 accessory plate options
    [food_caddy_k1se_accessories_everything_v2.stl, food_caddy_k1se_failed_only_v2.stl]
2026-09-11 Consolidate v2 designs as standard; reinforce lid tabs; add no-rails plate
    [food_caddy_k1se_accessories_everything.stl, food_caddy_k1se_accessories_everything_bed_centered.stl, food_caddy_k1se_accessories_no_rails.stl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]
2026-09-11 Fix lid knuckle geometry floating 0.3mm off bed
    The rear hinge knuckle tube dipped below z=0 in local coordinates, forcing onBed() to lift the entire lid off the print bed and causing bad first layers on the test print.
    [food_caddy_k1se_flip_lid_216mm.stl, food_caddy_k1se_flip_lid_216mm_bed_centered.stl]
2026-09-11 Rebuild food caddy with validated solid geometry and fit-test kit
    Archive the legacy designs; add R3 internal-ledge suspension, mating hardware, independent mesh checks and reproducible full/no-rails packages.
    [food_caddy_k1se_accessories_everything.stl, food_caddy_k1se_accessories_everything_bed_centered.stl, food_caddy_k1se_accessories_no_rails.stl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]
2026-09-12 Add all-printed R4 caddy and preserve metal-fastener R3 fallback
    Replace metal mounting and hinge hardware with stopped printed slides, rigid keepers and a captive printed axle. Include screw-free fit coupons, complete and no-rails packages, assembly checks and byte-preserved R3 fallback.
    [food_caddy_k1se_accessories_everything.stl, food_caddy_k1se_accessories_everything_bed_centered.stl, food_caddy_k1se_accessories_no_rails.stl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]
2026-09-12 Consolidate R4 printing into three production plates and one fit kit
    Nest unchanged accessory solids inside the liner frame with projected-footprint clearance checks. Retain individual spares and a separate no-rails alternative; update packages, quantities and print instructions.
    [r4-03-accessories-no-rails.stl, r4-03-accessories.stl, r4-03-liner-frame.stl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]
